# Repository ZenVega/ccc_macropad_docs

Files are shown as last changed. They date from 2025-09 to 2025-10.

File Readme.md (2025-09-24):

# CCC macropad

## Installation

### QMK Cli
This is just a quick recap. When you get stuck, check the official qmk documentation [here](https://docs.qmk.fm/newbs_getting_started)
In order to get QMK installed on your system run
'python3 -m pip install qmk'
Test if installation was successfull:
'qmk --version'

If you want to start from scratch follow the upcoming instructions. In case you just want to flash your macropad jump [here](#flash_build).

### QMK Setup

'qmk setup'
this will install the qmk firmware
submit prompts with 'y'

You should now have QMK setup in '~/qmk_firmware'.

### Create new layout
```bash
cd ~/qmk_firmware/keyboards
qmk new-keyboard
```

follow the instructions. when it comes to the board, choose: 

->non of the above layouts

->15. promicro_rp2040

your new keyboard's setup should now be created in: 

```bash
~/qmk_firmware/keyboards/<your_keyboards_name_folder>
```

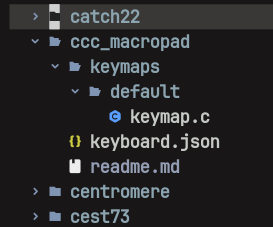
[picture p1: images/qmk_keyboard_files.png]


in you keyboard.json:
add: 
```yaml
"via": true
``` 
to the features

add: 
```yaml
  "analog": {
    "pins": ["GP26"]
  },
```
This adds the potential use of variable resistors connected to pin26.

The 'keyboard.yaml' holds the actual layout of the keyboard as well as some more metadata.
You may have multiple keymaps holding different configurations for this layout.
After configuring your keymap to your liking, you can always try to compile and see if you keymap.c and you kayboard.yaml align:

### Flash macropad {# flash_build}
However if you want to work with the layout we provide clone this [repo] (https://github.com/ZenVega/qmk_for_macropad/tree/main) containing the firmware and the macropad layout and keymap.
Or you use the cloned firmware and copy/past the all keyboard config files in the equivalent folder.
To install all missing dependencies run:

```bash
git submodule update --init --recursive

git submodule sync --recursive
git submodule update --init --recursive --force
```

### Compiling
This will create a *.bin that holds the firmware including your compilation ready to be flashed on the MCU

```bash
qmk compile -kb <keyboard> -km <keymap>
```
you should find a '<your_keyboard>

if not defined differently you keymap is just 'default'

### Flashing your MCU
Once you are ready to flash qmk to your microcontroller (rp2040 in this case), plug it in and set it into bootloader mode.
In our case that requires pressing the boot button while plugging it in. The device should show up as a flashable media in your files-explorer.
run:

```bash
qmk flash -kb <keyboard> -km <keymap>
```

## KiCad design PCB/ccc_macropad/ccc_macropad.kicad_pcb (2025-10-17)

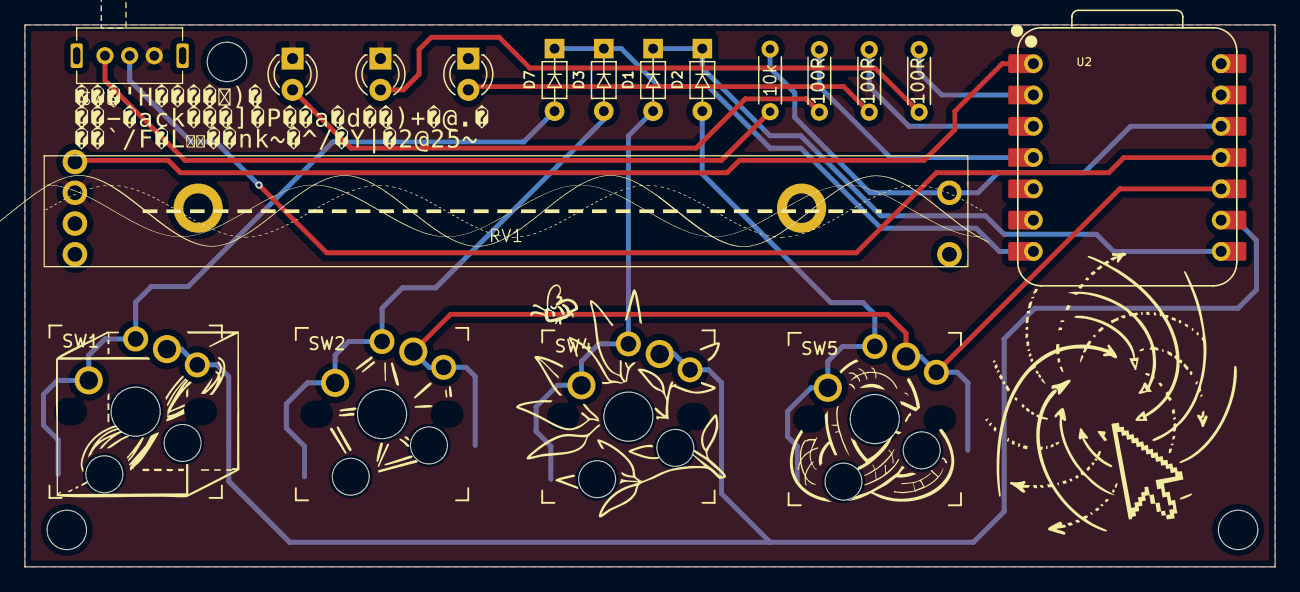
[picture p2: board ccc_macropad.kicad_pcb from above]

Board: 2 copper layers, 101.5 x 44.0 mm, 18 parts (0 on the bottom side), 19 nets.

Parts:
10k: 10k; R_Axial_DIN0204_L3.6mm_D1.6mm_P5.08mm_Horizontal
100R, 100R#2, 100R#3: 100R; R_Axial_DIN0204_L3.6mm_D1.6mm_P5.08mm_Horizontal
D1, D2, D3, D7: 1N4148WT; D_DO-35_SOD27_P5.08mm_Horizontal
D6 LED, D8 LED, D9 LED: LED; LED_D3.0mm
RV1: Analogue_input_slider 10k; Potentiometer_slide_75mm_range_60mm_2_sets
SW1, SW2, SW4, SW5: SW_Push; Kailh_socket_MX_PG1350_optional
SW3: OS/Left_Right-hand_Switch; SPDT_3pin_2_pos_1P2T_tht_2.54mm_switch_sk12d07
U2: XIAO-RP2040-DIP

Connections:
GND: D6 LED.1 (K), D8 LED.1 (K), D9 LED.1 (K), RV1.1, SW3.3 (A), U2.13 (GND)
unnamed: D1.2 (A), SW4.2
unnamed: D1.1 (K), D2.1 (K), U2.8 (GPIO1/RX)
unnamed: D2.2 (A), SW5.2
unnamed: D3.2 (A), SW2.2
unnamed: D3.1 (K), D7.1 (K), U2.7 (GPIO0/TX)
unnamed: 100R#3.1, D6 LED.2 (A)
unnamed: D7.2 (A), SW1.2
unnamed: 100R.1, D8 LED.2 (A)
unnamed: 100R#2.1, D9 LED.2 (A)
unnamed: SW3.2 (B), U2.11 (GPIO3/MOSI)
unnamed: 10k.1, SW3.1 (C)
unnamed: 10k.2, RV1.3, U2.12 (3V3)
unnamed: SW1.1, SW4.1, U2.9 (GPIO2/SCK)
unnamed: SW2.1, SW5.1, U2.10 (GPIO4/MISO)
unnamed: RV1.2, U2.1 (GPIO26/ADC0/A0)
unnamed: 100R#2.2, U2.2 (GPIO27/ADC1/A1)
unnamed: 100R.2, U2.3 (GPIO28/ADC2/A2)
unnamed: 100R#3.2, U2.4 (GPIO29/ADC3/A3)

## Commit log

2025-09-24 chores: add variable resistor to yaml
2025-09-24 kicad:feat: add schematics
    [ccc_macropad.kicad_pcb, ccc_macropad.kicad_sch]
2025-09-24 kicad:chores: remove backups from repo
2025-10-02 macropad:feature: add LED's and footprints
    [ccc_macropad.kicad_pcb, ccc_macropad.kicad_sch]
2025-10-02 feat: create BOM including order links
    [BOM.csv]
2025-10-02 feat: update BOM and OS_switch
    [BOM.csv, ccc_macropad.kicad_sch]
2025-10-04 feat: create and include all footprint. import all components in PCB
    [ccc_macropad.kicad_pcb, ccc_macropad.kicad_sch]
2025-10-10 PCB:feat: update footprint slider
    [ccc_macropad.kicad_pcb]
2025-10-10 PCB:feat: update footprint spdt switch
    [ccc_macropad.kicad_pcb]
2025-10-10 chores: font / fontsize
    [ccc_macropad.kicad_pcb]
2025-10-12 PCB:feat: add ground plane / add mounting holes / route thickness .4mm
    [ccc_macropad.kicad_pcb]
2025-10-16 fix: footprint switch / add ground plane front
    [ccc_macropad-B_Mask.gbr, ccc_macropad-B_Paste.gbr, ccc_macropad-B_Silkscreen.gbr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]
2025-10-16 chores: rm gerber zip
2025-10-16 rm font / add front ground plane
    [ccc_macropad.kicad_pcb]
2025-10-17 art for prototype added to KiCad
    [ccc_macropad.kicad_pcb]
2025-10-17 chores: add to .gitignore
    [ccc_macropad-B_Mask.gbr, ccc_macropad-B_Paste.gbr, ccc_macropad-B_Silkscreen.gbr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]
2025-10-17 extra: private notes and .gitignore
    [ccc_macropad-B_Mask.gbs, ccc_macropad-B_Paste.gbp, ccc_macropad-B_Silkscreen.gbo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]
